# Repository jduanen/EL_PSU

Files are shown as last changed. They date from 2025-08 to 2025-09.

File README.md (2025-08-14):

# EL_PSU
High Voltage Power Supply Unit for EL Displays

This is a modification of the most excellent work of Ben Krasnow at https://github.com/benkrasnow/EL_driver_multi

The primary motivation for these changes are to better support the needs of the EL displays found in https://github.com/jduanen/alienFontDisplay and https://github.com/jduanen/elClock.
In particular, to extend the life of these displays, I want to create a triangle (as opposed to, step) waveform so that the dv/dt of the signal exciting the display segments remains (close to) constant.

**WIP**

#### Parts Kitting

* Digikey Cart: https://www.digikey.com/short/m9prqmhq
  - look at datasheets and make sure substitutions work
    * B0540W Schottky diode not in stock at Digikey, substituting B0540W RHG
    * MMBD5004S-7DICT-ND is an obsolete item at Digikey

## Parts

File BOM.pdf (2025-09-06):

### Bill of Materials

ID | Part Number | Description | Qty.
HV Charge Circuit
TR1, TR2 | ATB3225 | Step-Up Transformer | 2
U2, U6 | LT3468 | Photoflash Charger | 2
D1, D2 | B0540W | 0.5A SOD123 SCHOTTKY BARRIER RECTIFIER | 2
D3, D4 | MMBD5004S | HIGH VOLTAGE DUAL SWITCHING DIODE | 2
C4 | - | 2.2flF 2220 (5750) SMD Capacitor | 1
C5, C9 | - | 6.3flF 0603 SMD Capacitor | 2
C6 | - | 100pF 0603 SMD Capacitor | 1
R2 | - | 10MOhm 0603 SMD Resistor | 1
R3 | - | 100kOhm 0603 SMD Resistor | 1
HV Control Circuit
U1 | HV513 | 8-Channel Low voltage serial to high voltage parallel IC | 1
| | OR
U9 | HV507 | 64-Channel Low voltage serial to high voltage parallel IC 1
LV Control Circuit | | All Components possibly from Tinket-M0
U? | ATSAMD21E Trinket M0 CPU | 1
U3 | AP2204K-3.3 | 3.3V Voltage regulator | 1
U4 | AP2204K-5.0 | 5.0V Voltage regulator | 1
C2, C3 | - | 1flF 0603 SMD Capacitor | 2
C1, C7, C8 | - | 10flF 0805 SMD Capacitor | 3
R1 | - | 1.5kOhm 0603 SMD Resistor | 1
R4 | - | 10kOhm 0603 SMD Resistor | 1
L1 | - | Red 0603 SMD LED | 1
PWR1 | - | Green Bright 0603 SMD LED | 1
Q2 | - | Tactile Switch SMT4.6X2.8 | 1
CN1 | - | Micro USB Female | 1

### Digikey Cart

Parts excluding 0603 caps and resistors, and microcontroller stuff: - Double quantity except for HV507 https://www.digikey.com/short/pc8p74 - Single quantity https://www.digikey.com/short/pc8p89

1

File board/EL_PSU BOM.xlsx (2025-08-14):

Reference | Value | Footprint | Datasheet | Qty | DNP | Exclude from BOM | Exclude from Board
C1,C7,C8 | 10uF | Trinket M0 rev D:0805-NO |  | 3
C2,C3 | 1uF | Trinket M0 rev D:0603-NO |  | 2
C5,C9 | 6.3uF | Trinket M0 rev D:0603-NO |  | 2
C6 | 100pF | Trinket M0 rev D:0603-NO |  | 1
CN1 | 4U#20329 | Trinket M0 rev D:4UCONN_20329_V2 |  | 1
IC3 | ATSAMD21E | Trinket M0 rev D:QFN32_5MM |  | 1
L1 | red | Trinket M0 rev D:CHIPLED_0603_NOOUTLINE |  | 1
PWR1 | green | Trinket M0 rev D:CHIPLED_0603_NOOUTLINE |  | 1
Q2 | reset | Trinket M0 rev D:BTN_KMR2_4.6X2.8 |  | 1
R1 | 1.5K | Trinket M0 rev D:0603-NO |  | 1
R2 | 10M | Trinket M0 rev D:0603-NO |  | 1
R3 | 100K | Trinket M0 rev D:0603-NO |  | 1
R4 | 10K | Trinket M0 rev D:0603-NO |  | 1
TR1,TR2 | ATB3225 | EL_driver:ATB3225 |  | 2
U2,U6 | LT3468 | Package_TO_SOT_SMD:SOT-23-5 |  | 2
U3 | AP2204K-3.3 | Package_TO_SOT_SMD:SOT-23-5 |  | 1
U4 | AP2204K-5.0 | Package_TO_SOT_SMD:SOT-23-5 |  | 1 |  | Diodes Incorporated | AP2210K-5.0TRG1
D1,D2 | B0540W | Diode_SMD:D_SOD-123 |  | 2
D3,D4 | MMBD5004S | Package_TO_SOT_SMD:SOT-23 |  | 2 |  | Toshiba | 1SS398TE85LF
TP1,TP2,TP3,TP4 | TestPoint | TestPoint:TestPoint_Pad_D1.0mm | ~ | 4
C4 | 2.2uF | Capacitor_SMD:C_2220_5650Metric |  | 1
J1,J2 | Conn_01x20_Female | Connector_PinHeader_1.27mm:PinHeader_1x20_P1.27mm_Vertical | ~ | 2
J3 | Conn_01x24_Female | Connector_PinHeader_1.27mm:PinHeader_1x24_P1.27mm_Vertical | ~ | 1
U1 | HV513 | Package_SO:SOIC-24W_7.5x15.4mm_P1.27mm |  | 1
U5 | HV507 | EL_driver:QFP-96_14x20_Pitch0.8mm |  | 1

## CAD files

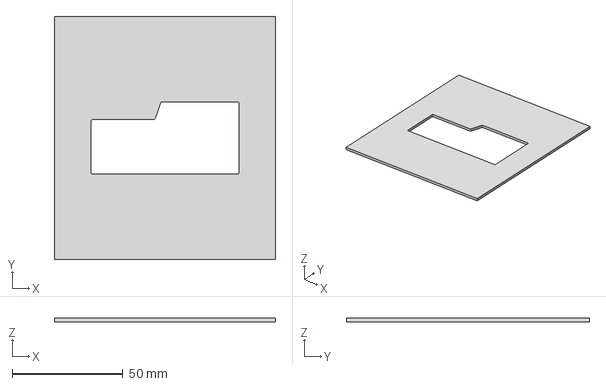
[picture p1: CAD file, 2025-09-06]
3D_models/EL_PSU_Jig.3mf
100.0 x 110.0 x 1.60 mm

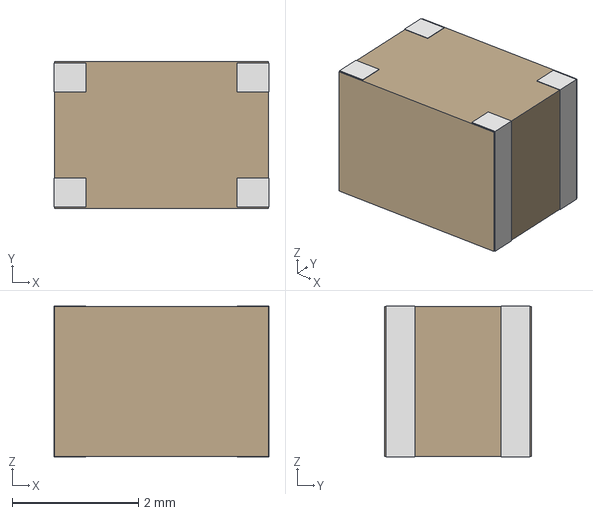
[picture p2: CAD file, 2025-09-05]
3D_models/CHOKE_524-0110-T000_TDK.step
3.40 x 2.33 x 2.39 mm

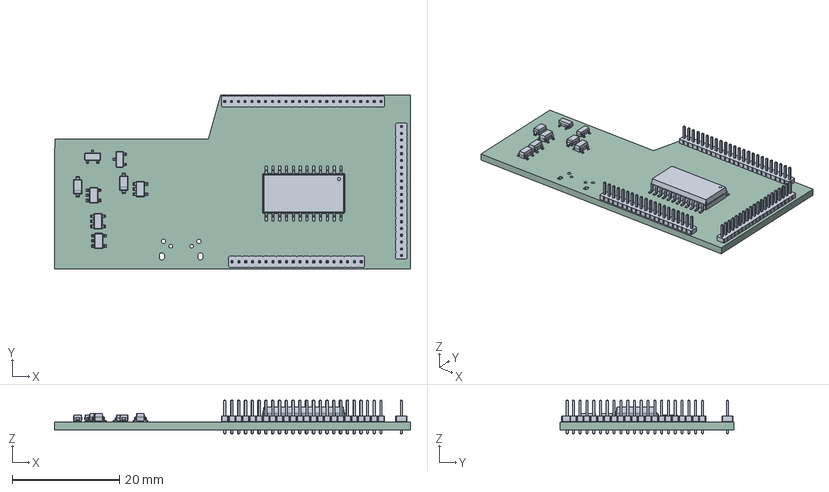
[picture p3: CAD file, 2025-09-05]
3D_models/EL_PSU.step
66.5 x 32.5 x 6.30 mm
SOT-23-5 x 4
D_SOD-123 x 2
SOIC-24W_7.5x15.4mm_P1.27mm
SOT-23 x 2
PinHeader_1x20_P1.27mm_Vertical x 2
PinHeader_1x24_P1.27mm_Vertical
EL_PSU_PCB

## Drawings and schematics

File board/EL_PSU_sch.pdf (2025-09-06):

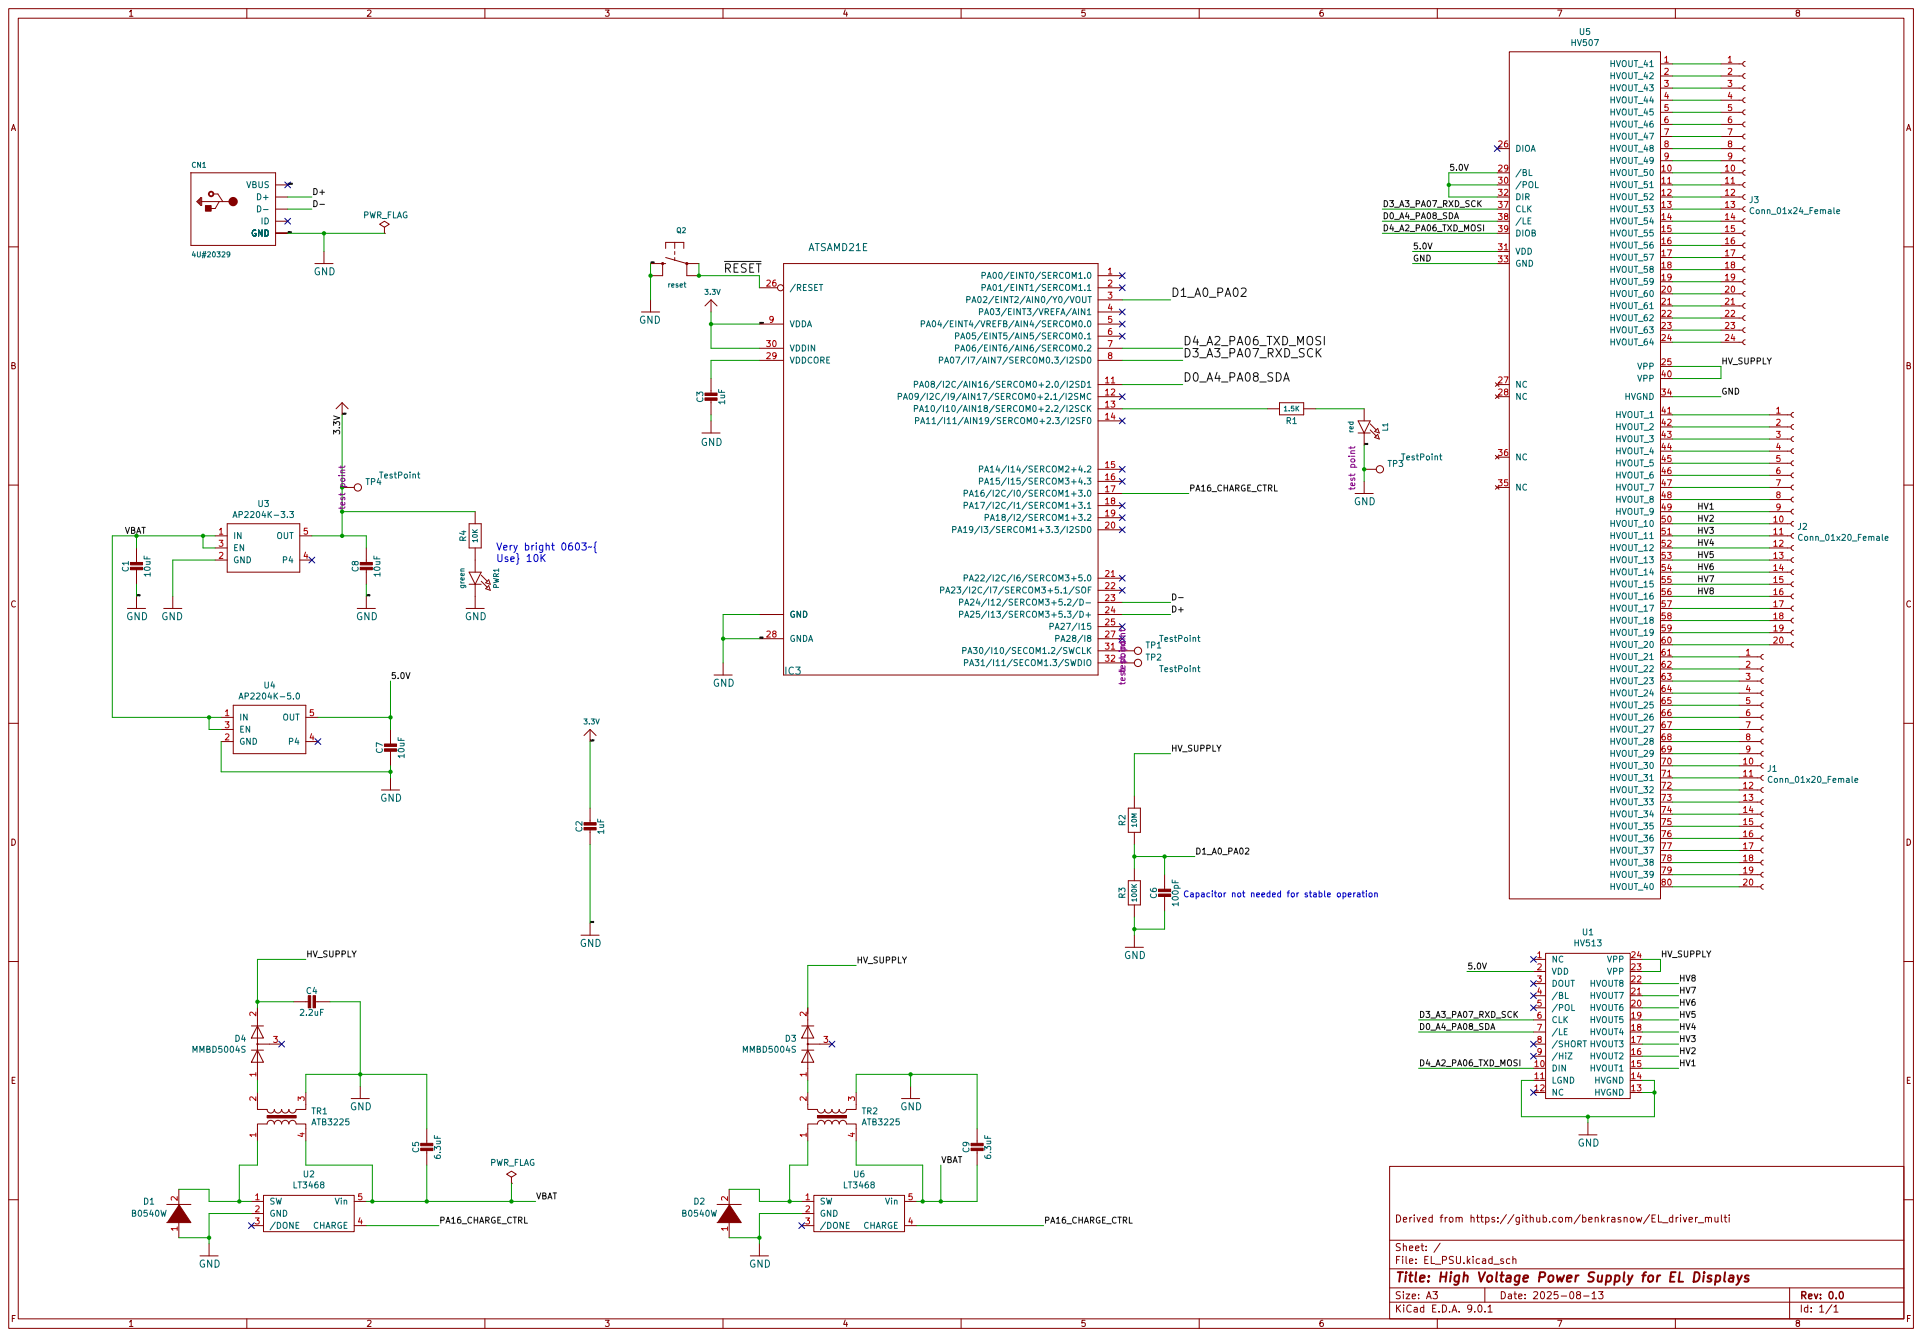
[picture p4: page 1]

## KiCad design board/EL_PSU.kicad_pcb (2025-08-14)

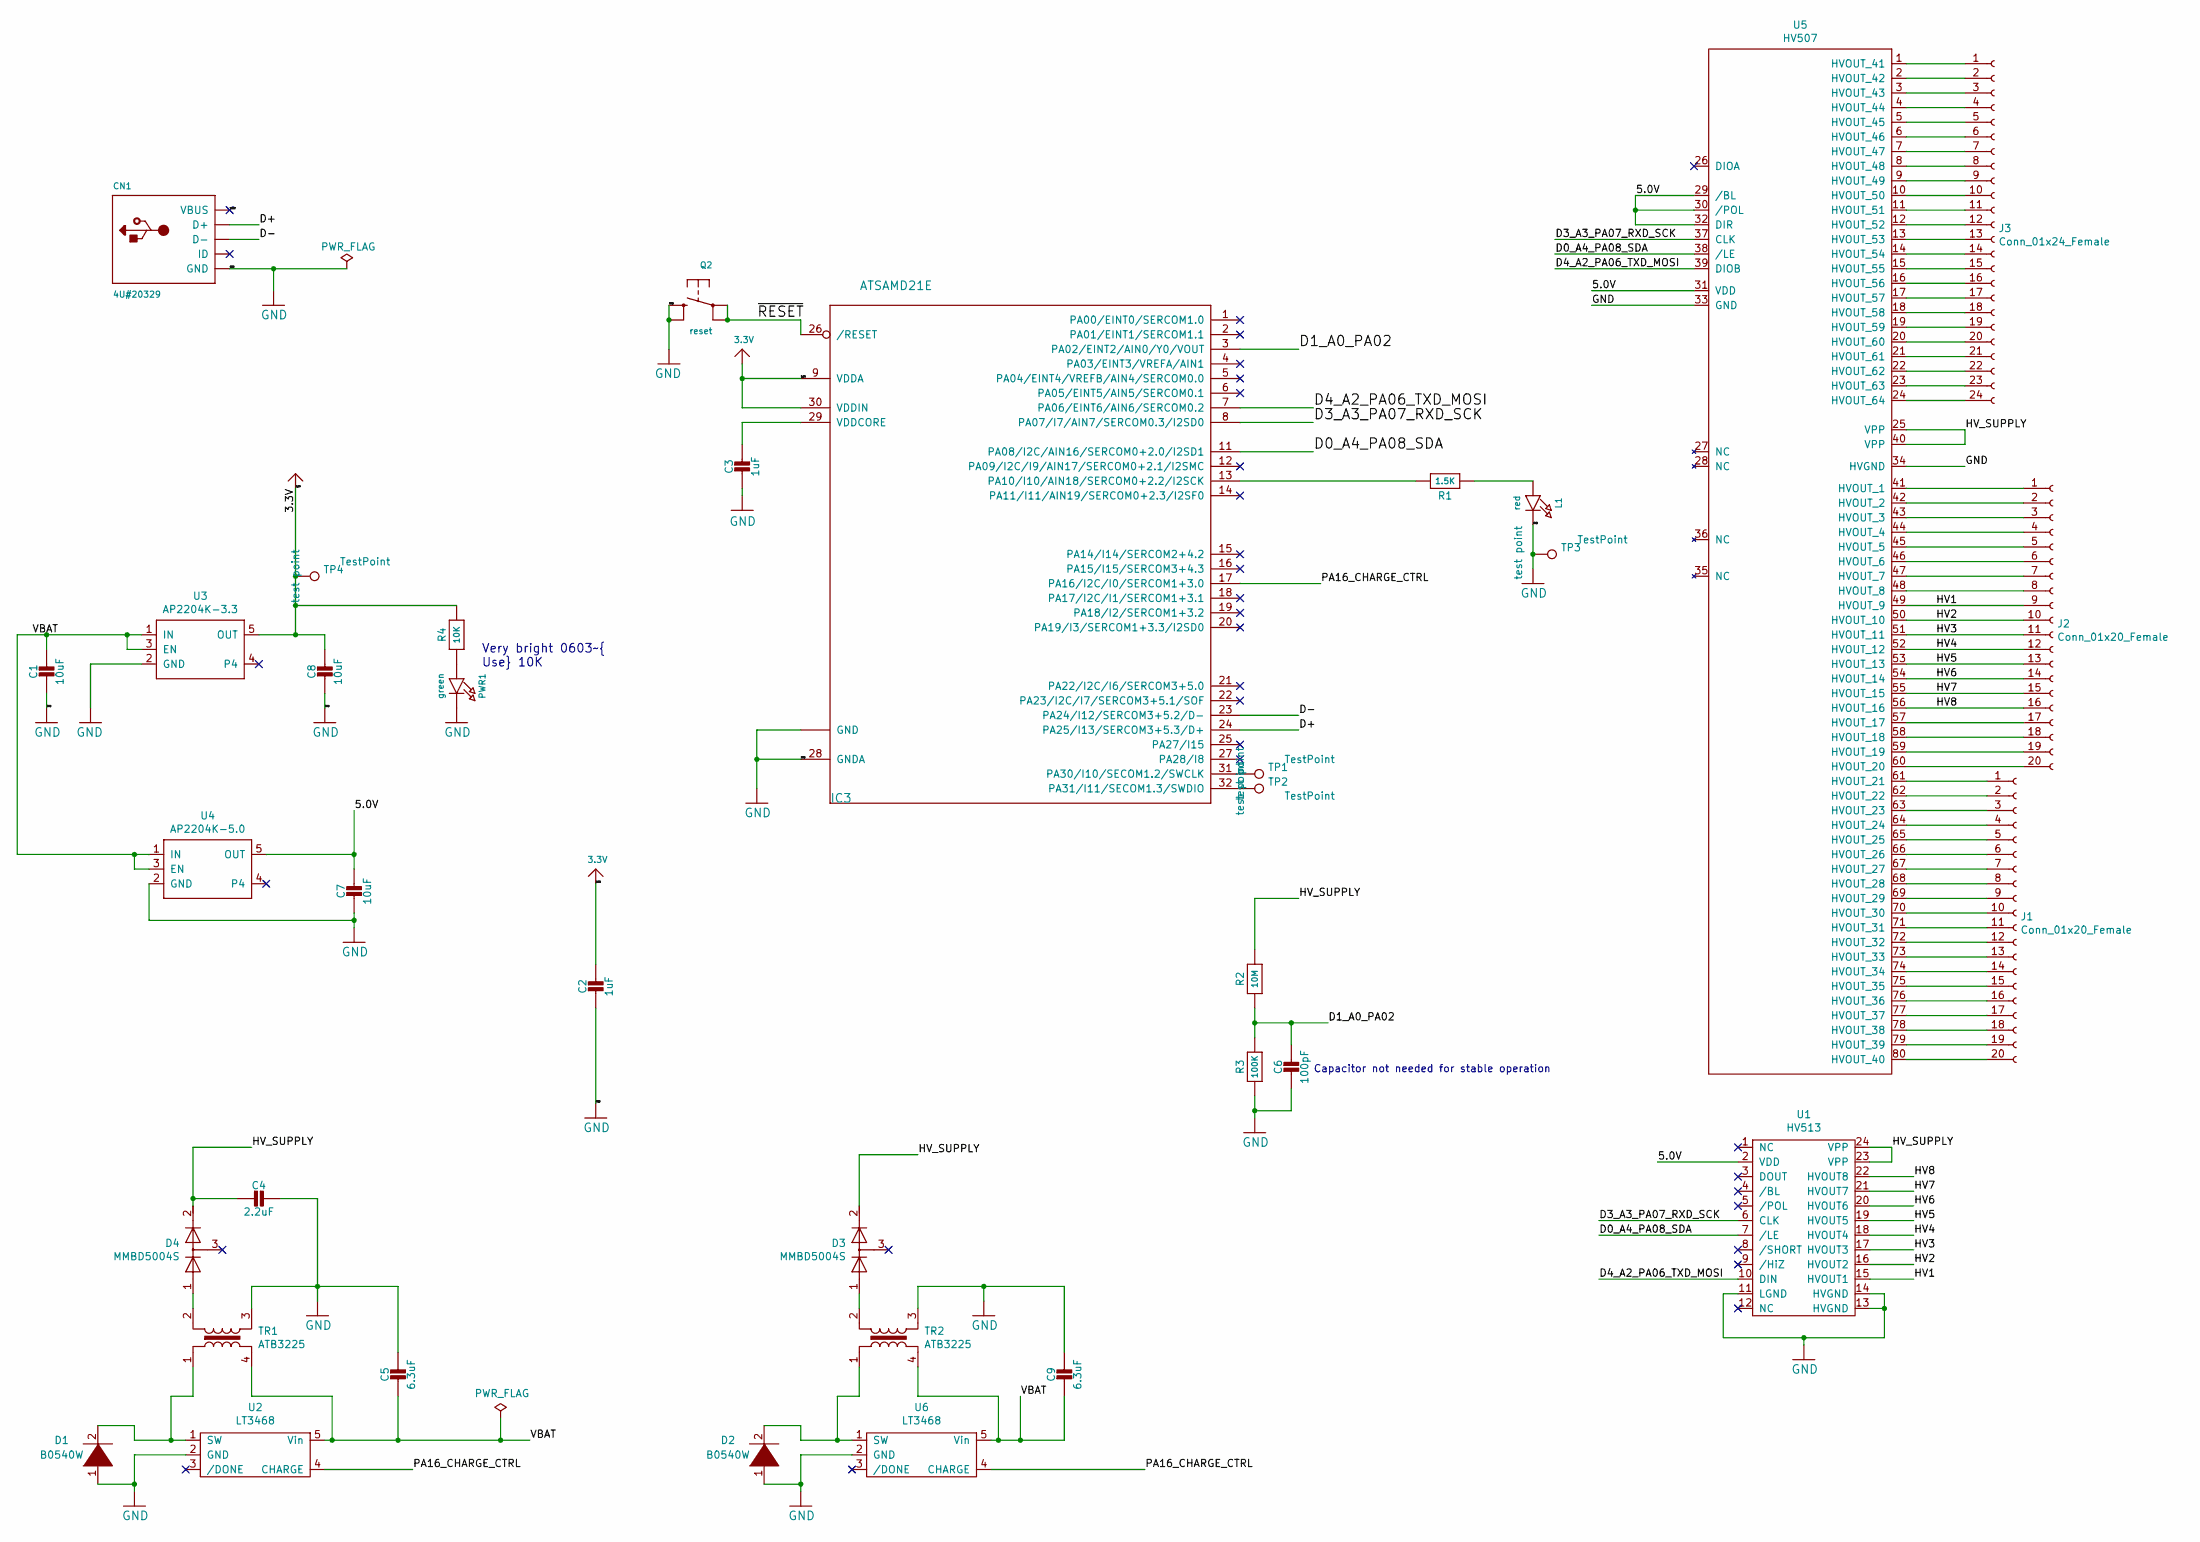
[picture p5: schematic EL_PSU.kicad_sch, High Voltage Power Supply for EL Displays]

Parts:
C1, C7, C8: 10uF; 0805-NO
C2, C3: 1uF; 0603-NO
C4: 2.2uF; C_2220_5650Metric
C5, C9: 6.3uF; 0603-NO
C6: 100pF; 0603-NO
CN1: 4U#20329; 4UCONN_20329_V2
D1, D2: B0540W; D_SOD-123
D3, D4: MMBD5004S; SOT-23
IC3: ATSAMD21E; QFN32_5MM
J1, J2: Conn_01x20_Female; PinHeader_1x20_P1.27mm_Vertical
J3: Conn_01x24_Female; PinHeader_1x24_P1.27mm_Vertical
L1: red; CHIPLED_0603_NOOUTLINE
PWR1: green; CHIPLED_0603_NOOUTLINE
Q2: reset; BTN_KMR2_4.6X2.8
R1: 1.5K; 0603-NO
R2: 10M; 0603-NO
R3: 100K; 0603-NO
R4: 10K; 0603-NO
TP1, TP2, TP3, TP4: TestPoint; TestPoint_Pad_D1.0mm
TR1, TR2: ATB3225
U1: HV513; SOIC-24W_7.5x15.4mm_P1.27mm
U2, U6: LT3468; SOT-23-5
U3: AP2204K-3.3; SOT-23-5
U4: AP2204K-5.0; SOT-23-5
U5: HV507; QFP-96_14x20_Pitch0.8mm

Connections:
3.3V: C2.1, C8.1, IC3.9 (VDDA), IC3.30 (VDDIN), R4.2, TP4.1, U3.5 (OUT)
/5.0V: C7.1, U1.2 (VDD), U4.5 (OUT), U5.29 (/BL), U5.30 (/POL), U5.31 (VDD), U5.32 (DIR)
/D0_A4_PA08_SDA: IC3.11 (PA08/I2C/AIN16/SERCOM0+2.0/I2SD1), U1.7 (/LE), U5.38 (/LE)
/D1_A0_PA02: C6.1, IC3.3 (PA02/EINT2/AIN0/Y0/VOUT), R2.1, R3.2
/D3_A3_PA07_RXD_SCK: IC3.8 (PA07/I7/AIN7/SERCOM0.3/I2SD0), U1.6 (CLK), U5.37 (CLK)
/D4_A2_PA06_TXD_MOSI: IC3.7 (PA06/EINT6/AIN6/SERCOM0.2), U1.10 (DIN), U5.39 (DIOB)
/D+: CN1.D+, IC3.24 (PA25/I13/SERCOM3+5.3/D+)
/D-: CN1.D-, IC3.23 (PA24/I12/SERCOM3+5.2/D-)
/HV1: J2.9, U1.15 (HVOUT1), U5.49 (HVOUT_9)
/HV2: J2.10, U1.16 (HVOUT2), U5.50 (HVOUT_10)
/HV3: J2.11, U1.17 (HVOUT3), U5.51 (HVOUT_11)
/HV4: J2.12, U1.18 (HVOUT4), U5.52 (HVOUT_12)
/HV5: J2.13, U1.19 (HVOUT5), U5.53 (HVOUT_13)
/HV6: J2.14, U1.20 (HVOUT6), U5.54 (HVOUT_14)
/HV7: J2.15, U1.21 (HVOUT7), U5.55 (HVOUT_15)
/HV8: J2.16, U1.22 (HVOUT8), U5.56 (HVOUT_16)
/HV_SUPPLY: C4.2, D3.2, D4.2, R2.2, U1.23 (VPP), U1.24 (VPP), U5.25 (VPP), U5.40 (VPP)
/PA16_CHARGE_CTRL: IC3.17 (PA16/I2C/I0/SERCOM1+3.0), U2.4 (CHARGE), U6.4 (CHARGE)
/VBAT: C1.1, C5.2, C9.2, TR1.4, TR2.4, U2.5 (Vin), U3.1 (IN), U3.3 (EN), U4.1 (IN), U4.3 (EN), U6.5 (Vin)
/VBUS: CN1.VBUS
/~RESET: IC3.26 (/RESET), Q2.A, Q2.A' (P1)
GND: C1.2, C2.2, C3.2, C4.1, C5.1, C6.2, C7.2, C8.2, C9.1, CN1.BASE@1 (GND), CN1.BASE@2 (GND), CN1.GND, CN1.SPRT@1 (GND), CN1.SPRT@2 (GND), CN1.SPRT@3 (GND), CN1.SPRT@4 (GND), D1.1 (K), D2.1 (K), IC3.10 (GND), IC3.28 (GNDA), IC3.33 (GND), L1.C, PWR1.C, Q2.B (S), Q2.B' (S1), R3.1, TP3.1, TR1.3, TR2.3, U1.11 (LGND), U1.13 (HVGND), U1.14 (HVGND), U2.2 (GND), U3.2 (GND), U4.2 (GND), U5.33 (GND), U5.34 (HVGND), U6.2 (GND)
unnamed: D1.2 (A), TR1.1, U2.1 (SW)
unnamed: D2.2 (A), TR2.1, U6.1 (SW)
unnamed: D3.1, TR2.2
unnamed: D4.1, TR1.2
unnamed: IC3.13 (PA10/I10/AIN18/SERCOM0+2.2/I2SCK), R1.2
unnamed: IC3.31 (PA30/I10/SECOM1.2/SWCLK), TP1.1
unnamed: IC3.32 (PA31/I11/SECOM1.3/SWDIO), TP2.1
unnamed: C3.1, IC3.29 (VDDCORE)
unnamed: J1.1, U5.61 (HVOUT_21)
unnamed: J1.2, U5.62 (HVOUT_22)
unnamed: J1.3, U5.63 (HVOUT_23)
unnamed: J1.4, U5.64 (HVOUT_24)
unnamed: J1.5, U5.65 (HVOUT_25)
unnamed: J1.6, U5.66 (HVOUT_26)
unnamed: J1.7, U5.67 (HVOUT_27)
unnamed: J1.8, U5.68 (HVOUT_28)
unnamed: J1.9, U5.69 (HVOUT_29)
unnamed: J1.10, U5.70 (HVOUT_30)
unnamed: J1.11, U5.71 (HVOUT_31)
unnamed: J1.12, U5.72 (HVOUT_32)
unnamed: J1.13, U5.73 (HVOUT_33)
unnamed: J1.14, U5.74 (HVOUT_34)
unnamed: J1.15, U5.75 (HVOUT_35)
unnamed: J1.16, U5.76 (HVOUT_36)
unnamed: J1.17, U5.77 (HVOUT_37)
unnamed: J1.18, U5.78 (HVOUT_38)
unnamed: J1.19, U5.79 (HVOUT_39)
unnamed: J1.20, U5.80 (HVOUT_40)
unnamed: J2.1, U5.41 (HVOUT_1)
unnamed: J2.2, U5.42 (HVOUT_2)
unnamed: J2.3, U5.43 (HVOUT_3)
unnamed: J2.4, U5.44 (HVOUT_4)
unnamed: J2.5, U5.45 (HVOUT_5)
unnamed: J2.6, U5.46 (HVOUT_6)
unnamed: J2.7, U5.47 (HVOUT_7)
unnamed: J2.8, U5.48 (HVOUT_8)
unnamed: J2.17, U5.57 (HVOUT_17)
unnamed: J2.18, U5.58 (HVOUT_18)
unnamed: J2.19, U5.59 (HVOUT_19)
unnamed: J2.20, U5.60 (HVOUT_20)
unnamed: J3.1, U5.1 (HVOUT_41)
unnamed: J3.2, U5.2 (HVOUT_42)
unnamed: J3.3, U5.3 (HVOUT_43)
unnamed: J3.4, U5.4 (HVOUT_44)
unnamed: J3.5, U5.5 (HVOUT_45)
unnamed: J3.6, U5.6 (HVOUT_46)
unnamed: J3.7, U5.7 (HVOUT_47)
unnamed: J3.8, U5.8 (HVOUT_48)
unnamed: J3.9, U5.9 (HVOUT_49)
unnamed: J3.10, U5.10 (HVOUT_50)
unnamed: J3.11, U5.11 (HVOUT_51)
unnamed: J3.12, U5.12 (HVOUT_52)
unnamed: J3.13, U5.13 (HVOUT_53)
unnamed: J3.14, U5.14 (HVOUT_54)
unnamed: J3.15, U5.15 (HVOUT_55)
unnamed: J3.16, U5.16 (HVOUT_56)
unnamed: J3.17, U5.17 (HVOUT_57)
unnamed: J3.18, U5.18 (HVOUT_58)
unnamed: J3.19, U5.19 (HVOUT_59)
unnamed: J3.20, U5.20 (HVOUT_60)
unnamed: J3.21, U5.21 (HVOUT_61)
unnamed: J3.22, U5.22 (HVOUT_62)
unnamed: J3.23, U5.23 (HVOUT_63)
unnamed: J3.24, U5.24 (HVOUT_64)
unnamed: L1.A, R1.1
unnamed: PWR1.A, R4.1

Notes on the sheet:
Very bright 0603~{ Use} 10K
Capacitor not needed for stable operation

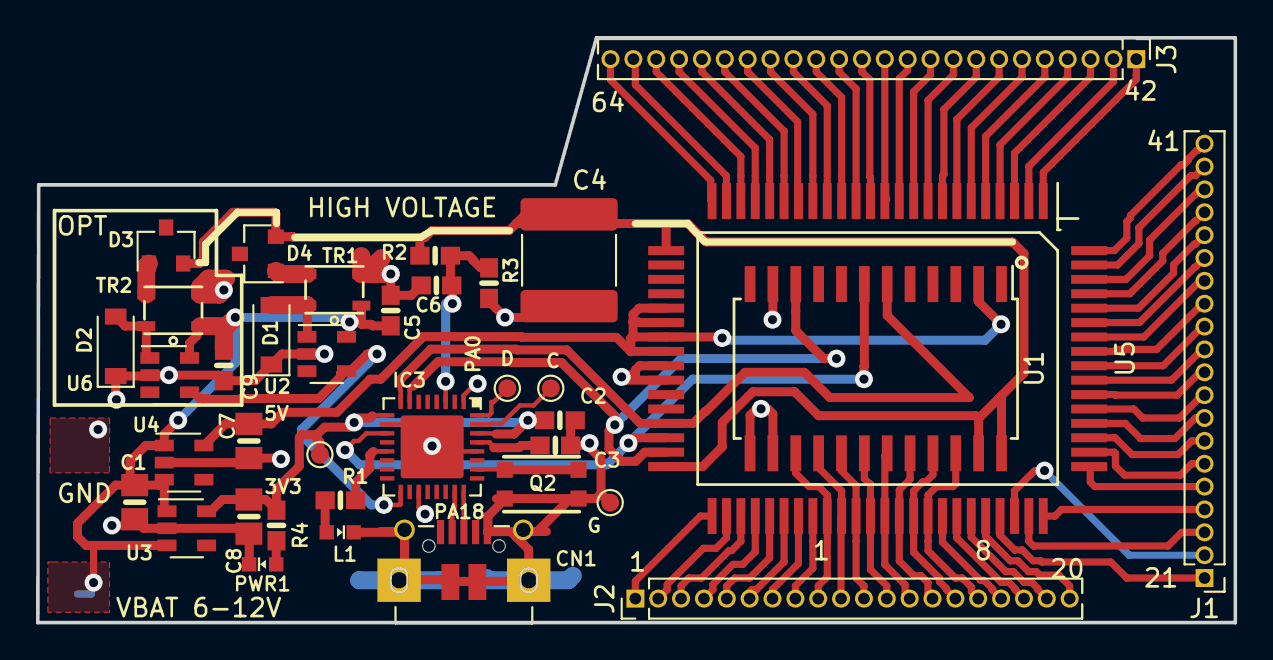
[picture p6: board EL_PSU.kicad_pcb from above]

Board: 2 copper layers, 66.5 x 32.5 mm, 37 parts (0 on the bottom side), 87 nets.

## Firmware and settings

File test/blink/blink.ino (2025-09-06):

/*
* Just blink the Green LED
*/

#define PIN_GREEN_LED	12  // PA10


bool state = false;


void setup () {
	pinMode(PIN_GREEN_LED, OUTPUT);
	digitalWrite(PIN_GREEN_LED, LOW);
};


void loop() {
	if (state) {
		state = false;
	} else {
		state = true;
	};
	digitalWrite(PIN_GREEN_LED, state);
	delay(1000);
};
